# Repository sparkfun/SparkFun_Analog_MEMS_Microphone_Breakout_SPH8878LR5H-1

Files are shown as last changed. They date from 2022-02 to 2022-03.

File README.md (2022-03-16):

SparkFun Analog MEMS Microphone Breakout - SPH8878LR5H-1
========================================

SparkFun MEMS Microphone Breakout (ICS-40180) (https://www.sparkfun.com/products/19389)

[*SparkFun MEMS Microphone Breakout (ICS-40180) [BOB-18011]*](https://www.sparkfun.com/products/19389)

The SparkFun Analog MEMS Microphone Breakout makes it easy to work with the SPH8878LR5H-1 analog microphone from Knowles. This board features an OpAmp to bring output of the microphone to a usable level, allowing you to plug directly into an ADC on a microcontroller or something like the [SparkFun Spectrum Shield](https://www.sparkfun.com/products/13116).

In addition to amplifying the signal, the OpAmp adds a bias voltage of 1/2 VCC. With sound sources such as a normal speaking voice a few feet away from the microphone, the AUD output signal will be at about 200mV peak-to-peak. Also note, this low profile microphone has its port on the bottom side, so the microphone can be mounted flush to the outer surface of your enclosure. This microphone is omni-directional, which means it does a good job of picking up sound sources from all directions.

Repository Contents
-------------------

* **/Documentation** - Data sheets, additional product information
* **/Hardware** - Eagle design files (.brd, .sch)
* **/Hardware/Production** - Production panel files (.brd)

Documentation
--------------
* **[Hookup Guide](https://learn.sparkfun.com/tutorials/analog-mems-microphone-breakout---sph8878lr5h-1-hookup-guide)** - Basic hookup guide for the SparkFun MEMS microphone breakout.

Product Versions
---------------
* **[BOB-09868](https://www.sparkfun.com/products/retired/9868)** - SparkFun MEMS Microphone Breakout - INMP401 (ADMP401)
* **[BOB-18011](https://www.sparkfun.com/products/18011)** - SparkFun Analog MEMS Microphone Breakout - ICS-40180 
* **[BOB-19389](https://www.sparkfun.com/products/19389)** -  SparkFun Analog MEMS Microphone Breakout - SPH8878LR5H-1

License Information
-------------------

This product is _**open source**_! 

Please review the LICENSE.md file for license information. 

If you have any questions or concerns on licensing, please contact technical support on our [SparkFun forums](https://forum.sparkfun.com/viewforum.php?f=152).

Distributed as-is; no warranty is given.

- Your friends at SparkFun.

_<COLLABORATION CREDIT>_

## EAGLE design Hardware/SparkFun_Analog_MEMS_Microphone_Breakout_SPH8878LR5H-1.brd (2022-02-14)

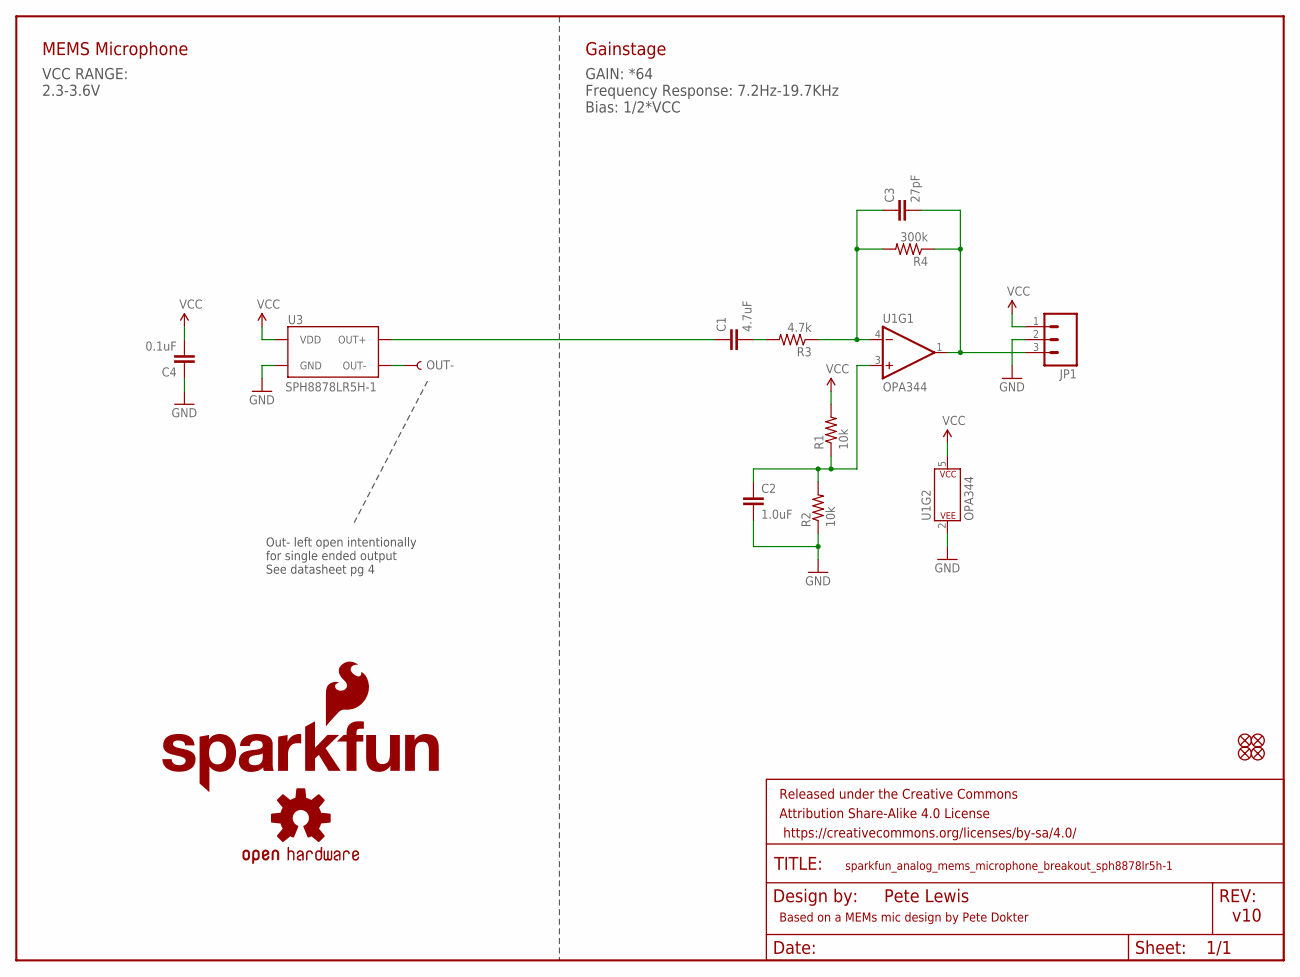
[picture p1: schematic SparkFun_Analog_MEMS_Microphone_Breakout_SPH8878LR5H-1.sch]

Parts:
C1: 4.7uF; 0603
C2: 1.0uF; 0603
C3: 27pF; 0603
C4: 0.1uF; 0603
FD1, FD2, FD3, FD4: FIDUCIALUFIDUCIAL; FIDUCIAL-MICRO
FRAME2: FRAME-LETTER; CREATIVE_COMMONS
JP1: CONN_031X03_NO_SILK; 1X03_NO_SILK
LOGO1: SFE_LOGO_FLAME.1_INCH; SFE_LOGO_FLAME_.1
LOGO2: OSHW-LOGOMINI; OSHW-LOGO-MINI
OUT-: TEST-POINTTP_15TH_THRU; TP_15TH
R1, R2: 10k; 0603
R3: 4.7k; 0603
R4: 300k; 0603
U1: OPA344; SOT23-5
U3: SPH8878LR5H-1

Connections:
AUD: C3.2, JP1.3, R4.1, U1.1 (OUT)
GND: C2.2, C4.1, JP1.2, R2.1, U1.2 (P$V-), U3.2 (GND), U3.3 (GND), U3.4 (GND)
unnamed: C1.1, U3.1 (OUT+)
unnamed: C3.1, R3.1, R4.2, U1.4 (-IN)
unnamed: OUT-.1, U3.6 (OUT-)
unnamed: C1.2, R3.2
unnamed: C2.1, R1.1, R2.2, U1.3 (+IN)
VCC: C4.2, JP1.1, R1.2, U1.5 (P$V+), U3.5 (VDD)

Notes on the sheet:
v10
Pete Lewis
VCC RANGE: 2.3-3.6V
MEMS Microphone
Gainstage
GAIN: *64 Frequency Response: 7.2Hz-19.7KHz Bias: 1/2*VCC
Out- left open intentionally for single ended output See datasheet pg 4
Based on a MEMs mic design by Pete Dokter

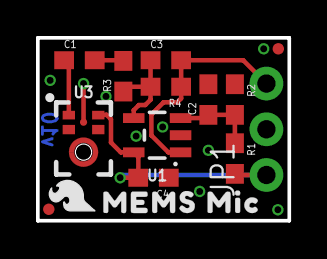
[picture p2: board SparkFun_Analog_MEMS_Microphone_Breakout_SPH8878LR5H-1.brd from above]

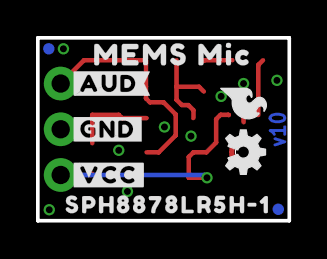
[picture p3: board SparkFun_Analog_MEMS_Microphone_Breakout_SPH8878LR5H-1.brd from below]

Board: 2 copper layers, 14.0 x 10.2 mm, 26 parts (10 on the bottom side), 8 nets.

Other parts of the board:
LOGO3: SFE_LOGO_FLAME.1_INCH; SFE_LOGO_FLAME_.1
U$2, U$7: MEMS_MIC0
U$3: #GND#0
U$4: #VCC#0
U$5: #AUD#0
U$9: SPH8878LR5H#10

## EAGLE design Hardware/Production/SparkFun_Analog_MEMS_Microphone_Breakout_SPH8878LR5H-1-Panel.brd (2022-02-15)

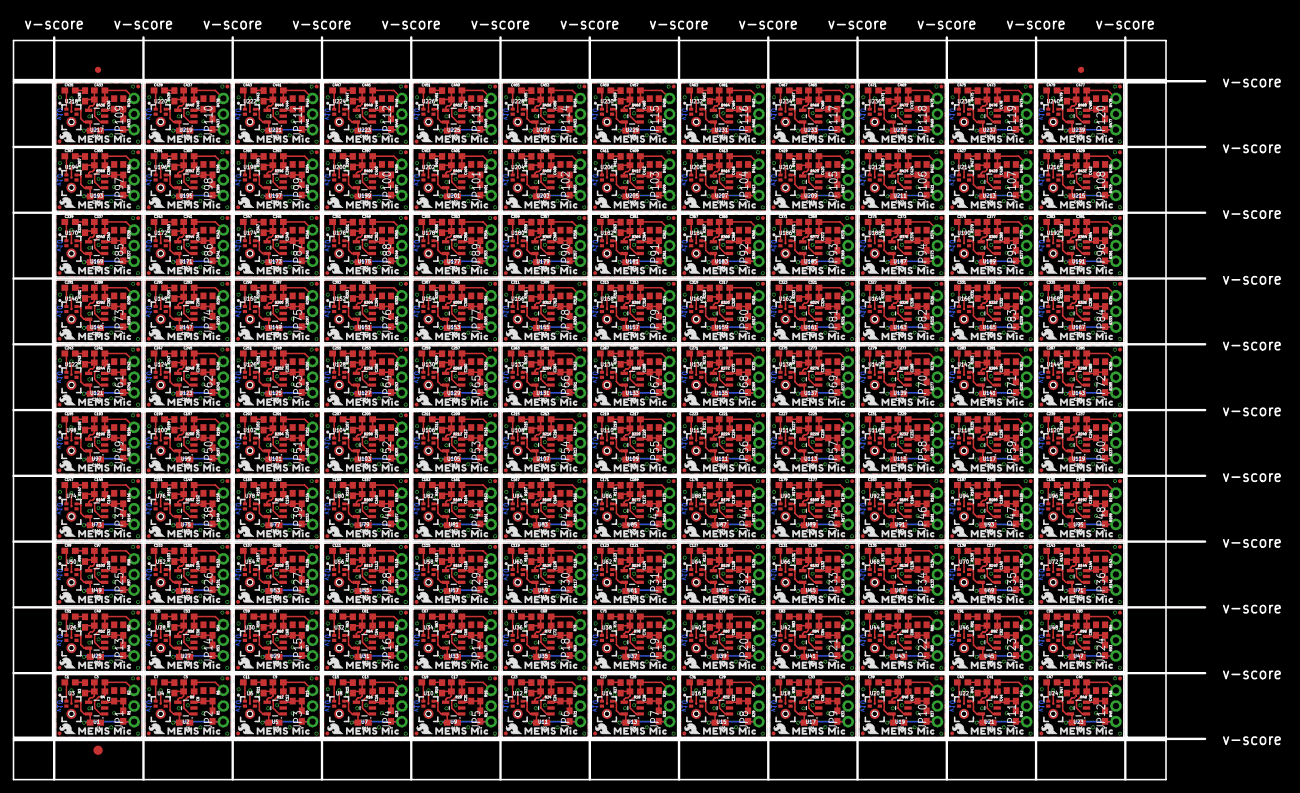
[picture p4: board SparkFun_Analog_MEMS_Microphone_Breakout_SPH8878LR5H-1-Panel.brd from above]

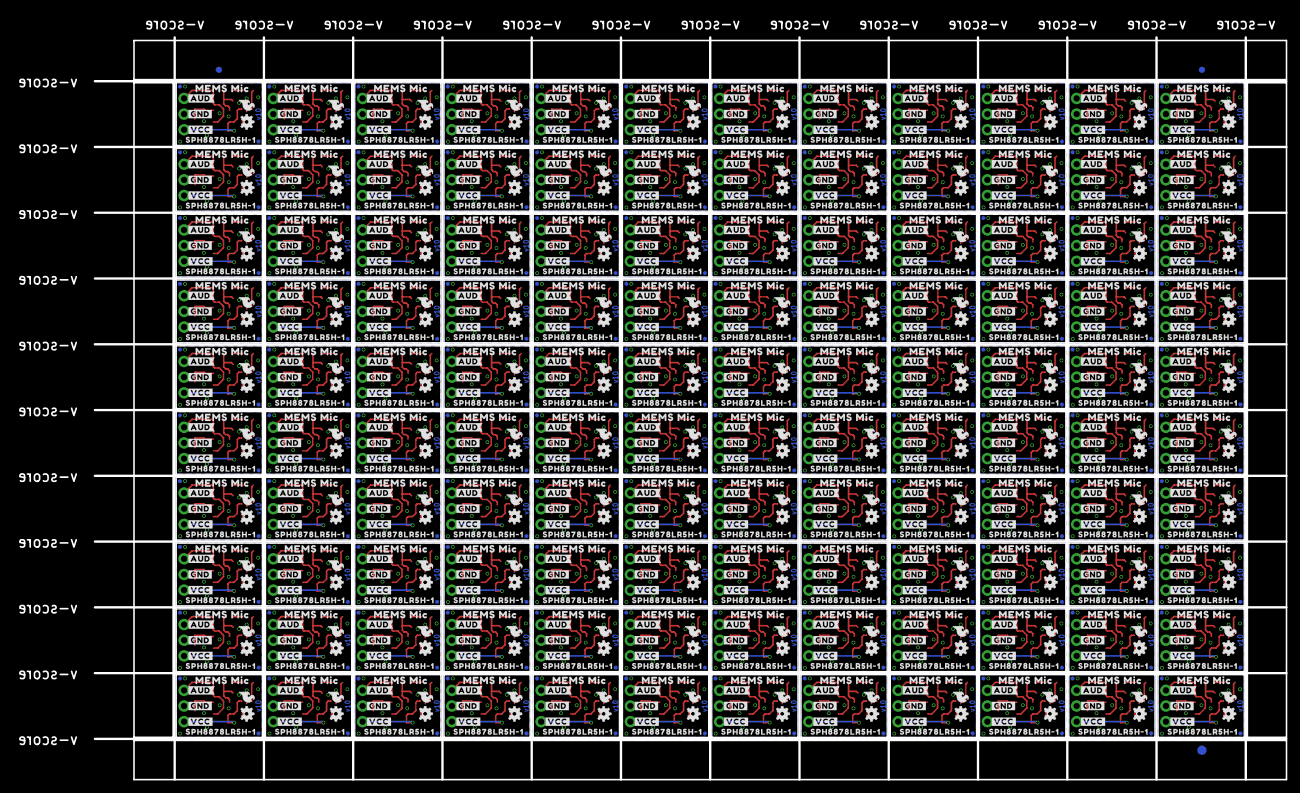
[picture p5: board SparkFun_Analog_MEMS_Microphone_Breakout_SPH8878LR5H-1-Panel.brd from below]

Board: 2 copper layers, 193.3 x 120.4 mm, 3006 parts (1203 on the bottom side), 960 nets.

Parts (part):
C1, C7, C11, C15, C19, C23, C27, C31, C35, C39, C43, C47, C51, C55, C59, C63, C67, C71, C75, C79, C83, C87, C91, C95, C99, C103, C107, C111, C115, C119, C123, C127, C131, C135, C139, C143, C147, C151, C155, C159, C163, C167, C171, C175, C179, C183, C187, C191, C195, C199, C203, C207, C211, C215, C219, C223, C227, C231, C235, C239, C243, C247, C251, C255, C259, C263, C267, C271, C275, C279, C283, C287, C291, C295, C299, C303, C307, C311, C315, C319, C323, C327, C331, C335, C339, C343, C347, C351, C355, C359, C363, C367, C371, C375, C379, C383, C387, C391, C395, C399, C403, C407, C411, C415, C419, C423, C427, C431, C435, C439, C443, C447, C451, C455, C459, C463, C467, C471, C475, C479: 4.7uF; 0603
C2, C8, C12, C16, C20, C24, C28, C32, C36, C40, C44, C48, C52, C56, C60, C64, C68, C72, C76, C80, C84, C88, C92, C96, C100, C104, C108, C112, C116, C120, C124, C128, C132, C136, C140, C144, C148, C152, C156, C160, C164, C168, C172, C176, C180, C184, C188, C192, C196, C200, C204, C208, C212, C216, C220, C224, C228, C232, C236, C240, C244, C248, C252, C256, C260, C264, C268, C272, C276, C280, C284, C288, C292, C296, C300, C304, C308, C312, C316, C320, C324, C328, C332, C336, C340, C344, C348, C352, C356, C360, C364, C368, C372, C376, C380, C384, C388, C392, C396, C400, C404, C408, C412, C416, C420, C424, C428, C432, C436, C440, C444, C448, C452, C456, C460, C464, C468, C472, C476, C480: 1.0uF; 0603
C3, C5, C9, C13, C17, C21, C25, C29, C33, C37, C41, C45, C49, C53, C57, C61, C65, C69, C73, C77, C81, C85, C89, C93, C97, C101, C105, C109, C113, C117, C121, C125, C129, C133, C137, C141, C145, C149, C153, C157, C161, C165, C169, C173, C177, C181, C185, C189, C193, C197, C201, C205, C209, C213, C217, C221, C225, C229, C233, C237, C241, C245, C249, C253, C257, C261, C265, C269, C273, C277, C281, C285, C289, C293, C297, C301, C305, C309, C313, C317, C321, C325, C329, C333, C337, C341, C345, C349, C353, C357, C361, C365, C369, C373, C377, C381, C385, C389, C393, C397, C401, C405, C409, C413, C417, C421, C425, C429, C433, C437, C441, C445, C449, C453, C457, C461, C465, C469, C473, C477: 27pF; 0603
C4, C6, C10, C14, C18, C22, C26, C30, C34, C38, C42, C46, C50, C54, C58, C62, C66, C70, C74, C78, C82, C86, C90, C94, C98, C102, C106, C110, C114, C118, C122, C126, C130, C134, C138, C142, C146, C150, C154, C158, C162, C166, C170, C174, C178, C182, C186, C190, C194, C198, C202, C206, C210, C214, C218, C222, C226, C230, C234, C238, C242, C246, C250, C254, C258, C262, C266, C270, C274, C278, C282, C286, C290, C294, C298, C302, C306, C310, C314, C318, C322, C326, C330, C334, C338, C342, C346, C350, C354, C358, C362, C366, C370, C374, C378, C382, C386, C390, C394, C398, C402, C406, C410, C414, C418, C422, C426, C430, C434, C438, C442, C446, C450, C454, C458, C462, C466, C470, C474, C478: 0.1uF; 0603
E$1, E$2, E$3, E$4: FIDUCIAL-1X2
E$5, E$6: FIDUCIAL-1.5X3
FD1, FD2, FD3, FD4, FD5, FD6, FD7, FD8, FD9, FD10, FD11, FD12, FD13, FD14, FD15, FD16, FD17, FD18, FD19, FD20, FD21, FD22, FD23, FD24, FD25, FD26, FD27, FD28, FD29, FD30, FD31, FD32, FD33, FD34, FD35, FD36, FD37, FD38, FD39, FD40, FD41, FD42, FD43, FD44, FD45, FD46, FD47, FD48, FD49, FD50, FD51, FD52, FD53, FD54, FD55, FD56, FD57, FD58, FD59, FD60, FD61, FD62, FD63, FD64, FD65, FD66, FD67, FD68, FD69, FD70, FD71, FD72, FD73, FD74, FD75, FD76, FD77, FD78, FD79, FD80, FD81, FD82, FD83, FD84, FD85, FD86, FD87, FD88, FD89, FD90, FD91, FD92, FD93, FD94, FD95, FD96, FD97, FD98, FD99, FD100, FD101, FD102, FD103, FD104, FD105, FD106, FD107, FD108, FD109, FD110, FD111, FD112, FD113, FD114, FD115, FD116, FD117, FD118, FD119, FD120, FD121, FD122, FD123, FD124, FD125, FD126, FD127, FD128, FD129, FD130, FD131, FD132, FD133, FD134, FD135, FD136, FD137, FD138, FD139, FD140, FD141, FD142, FD143, FD144, FD145, FD146, FD147, FD148, FD149, FD150, FD151, FD152, FD153, FD154, FD155, FD156, FD157, FD158, FD159, FD160, FD161, FD162, FD163, FD164, FD165, FD166, FD167, FD168, FD169, FD170, FD171, FD172, FD173, FD174, FD175, FD176, FD177, FD178, FD179, FD180, FD181, FD182, FD183, FD184, FD185, FD186, FD187, FD188, FD189, FD190, FD191, FD192, FD193, FD194, FD195, FD196, FD197, FD198, FD199, FD200, FD201, FD202, FD203, FD204, FD205, FD206, FD207, FD208, FD209, FD210, FD211, FD212, FD213, FD214, FD215, FD216, FD217, FD218, FD219, FD220, FD221, FD222, FD223, FD224, FD225, FD226, FD227, FD228, FD229, FD230, FD231, FD232, FD233, FD234, FD235, FD236, FD237, FD238, FD239, FD240, FD241, FD242, FD243, FD244, FD245, FD246, FD247, FD248, FD249, FD250, FD251, FD252, FD253, FD254, FD255, FD256, FD257, FD258, FD259, FD260, FD261, FD262, FD263, FD264, FD265, FD266, FD267, FD268, FD269, FD270, FD271, FD272, FD273, FD274, FD275, FD276, FD277, FD278, FD279, FD280, FD281, FD282, FD283, FD284, FD285, FD286, FD287, FD288, FD289, FD290, FD291, FD292, FD293, FD294, FD295, FD296, FD297, FD298, FD299, FD300, FD301, FD302, FD303, FD304, FD305, FD306, FD307, FD308, FD309, FD310, FD311, FD312, FD313, FD314, FD315, FD316, FD317, FD318, FD319, FD320, FD321, FD322, FD323, FD324, FD325, FD326, FD327, FD328, FD329, FD330, FD331, FD332, FD333, FD334, FD335, FD336, FD337, FD338, FD339, FD340, FD341, FD342, FD343, FD344, FD345, FD346, FD347, FD348, FD349, FD350, FD351, FD352, FD353, FD354, FD355, FD356, FD357, FD358, FD359, FD360, FD361, FD362, FD363, FD364, FD365, FD366, FD367, FD368, FD369, FD370, FD371, FD372, FD373, FD374, FD375, FD376, FD377, FD378, FD379, FD380, FD381, FD382, FD383, FD384, FD385, FD386, FD387, FD388, FD389, FD390, FD391, FD392, FD393, FD394, FD395, FD396, FD397, FD398, FD399, FD400, FD401, FD402, FD403, FD404, FD405, FD406, FD407, FD408, FD409, FD410, FD411, FD412, FD413, FD414, FD415, FD416, FD417, FD418, FD419, FD420, FD421, FD422, FD423, FD424, FD425, FD426, FD427, FD428, FD429, FD430, FD431, FD432, FD433, FD434, FD435, FD436, FD437, FD438, FD439, FD440, FD441, FD442, FD443, FD444, FD445, FD446, FD447, FD448, FD449, FD450, FD451, FD452, FD453, FD454, FD455, FD456, FD457, FD458, FD459, FD460, FD461, FD462, FD463, FD464, FD465, FD466, FD467, FD468, FD469, FD470, FD471, FD472, FD473, FD474, FD475, FD476, FD477, FD478, FD479, FD480: FIDUCIALUFIDUCIAL; FIDUCIAL-MICRO
JP1, JP2, JP3, JP4, JP5, JP6, JP7, JP8, JP9, JP10, JP11, JP12, JP13, JP14, JP15, JP16, JP17, JP18, JP19, JP20, JP21, JP22, JP23, JP24, JP25, JP26, JP27, JP28, JP29, JP30, JP31, JP32, JP33, JP34, JP35, JP36, JP37, JP38, JP39, JP40, JP41, JP42, JP43, JP44, JP45, JP46, JP47, JP48, JP49, JP50, JP51, JP52, JP53, JP54, JP55, JP56, JP57, JP58, JP59, JP60, JP61, JP62, JP63, JP64, JP65, JP66, JP67, JP68, JP69, JP70, JP71, JP72, JP73, JP74, JP75, JP76, JP77, JP78, JP79, JP80, JP81, JP82, JP83, JP84, JP85, JP86, JP87, JP88, JP89, JP90, JP91, JP92, JP93, JP94, JP95, JP96, JP97, JP98, JP99, JP100, JP101, JP102, JP103, JP104, JP105, JP106, JP107, JP108, JP109, JP110, JP111, JP112, JP113, JP114, JP115, JP116, JP117, JP118, JP119, JP120: 1X03_NO_SILK
LOGO1, LOGO3, LOGO4, LOGO6, LOGO7, LOGO9, LOGO10, LOGO12, LOGO13, LOGO15, LOGO16, LOGO18, LOGO19, LOGO21, LOGO22, LOGO24, LOGO25, LOGO27, LOGO28, LOGO30, LOGO31, LOGO33, LOGO34, LOGO36, LOGO37, LOGO39, LOGO40, LOGO42, LOGO43, LOGO45, LOGO46, LOGO48, LOGO49, LOGO51, LOGO52, LOGO54, LOGO55, LOGO57, LOGO58, LOGO60, LOGO61, LOGO63, LOGO64, LOGO66, LOGO67, LOGO69, LOGO70, LOGO72, LOGO73, LOGO75, LOGO76, LOGO78, LOGO79, LOGO81, LOGO82, LOGO84, LOGO85, LOGO87, LOGO88, LOGO90, LOGO91, LOGO93, LOGO94, LOGO96, LOGO97, LOGO99, LOGO100, LOGO102, LOGO103, LOGO105, LOGO106, LOGO108, LOGO109, LOGO111, LOGO112, LOGO114, LOGO115, LOGO117, LOGO118, LOGO120, LOGO121, LOGO123, LOGO124, LOGO126, LOGO127, LOGO129, LOGO130, LOGO132, LOGO133, LOGO135, LOGO136, LOGO138, LOGO139, LOGO141, LOGO142, LOGO144, LOGO145, LOGO147, LOGO148, LOGO150, LOGO151, LOGO153, LOGO154, LOGO156, LOGO157, LOGO159, LOGO160, LOGO162, LOGO163, LOGO165, LOGO166, LOGO168, LOGO169, LOGO171, LOGO172, LOGO174, LOGO175, LOGO177, LOGO178, LOGO180, LOGO181, LOGO183, LOGO184, LOGO186, LOGO187, LOGO189, LOGO190, LOGO192, LOGO193, LOGO195, LOGO196, LOGO198, LOGO199, LOGO201, LOGO202, LOGO204, LOGO205, LOGO207, LOGO208, LOGO210, LOGO211, LOGO213, LOGO214, LOGO216, LOGO217, LOGO219, LOGO220, LOGO222, LOGO223, LOGO225, LOGO226, LOGO228, LOGO229, LOGO231, LOGO232, LOGO234, LOGO235, LOGO237, LOGO238, LOGO240, LOGO241, LOGO243, LOGO244, LOGO246, LOGO247, LOGO249, LOGO250, LOGO252, LOGO253, LOGO255, LOGO256, LOGO258, LOGO259, LOGO261, LOGO262, LOGO264, LOGO265, LOGO267, LOGO268, LOGO270, LOGO271, LOGO273, LOGO274, LOGO276, LOGO277, LOGO279, LOGO280, LOGO282, LOGO283, LOGO285, LOGO286, LOGO288, LOGO289, LOGO291, LOGO292, LOGO294, LOGO295, LOGO297, LOGO298, LOGO300, LOGO301, LOGO303, LOGO304, LOGO306, LOGO307, LOGO309, LOGO310, LOGO312, LOGO313, LOGO315, LOGO316, LOGO318, LOGO319, LOGO321, LOGO322, LOGO324, LOGO325, LOGO327, LOGO328, LOGO330, LOGO331, LOGO333, LOGO334, LOGO336, LOGO337, LOGO339, LOGO340, LOGO342, LOGO343, LOGO345, LOGO346, LOGO348, LOGO349, LOGO351, LOGO352, LOGO354, LOGO355, LOGO357, LOGO358, LOGO360: SFE_LOGO_FLAME.1_INCH; SFE_LOGO_FLAME_.1
LOGO2, LOGO5, LOGO8, LOGO11, LOGO14, LOGO17, LOGO20, LOGO23, LOGO26, LOGO29, LOGO32, LOGO35, LOGO38, LOGO41, LOGO44, LOGO47, LOGO50, LOGO53, LOGO56, LOGO59, LOGO62, LOGO65, LOGO68, LOGO71, LOGO74, LOGO77, LOGO80, LOGO83, LOGO86, LOGO89, LOGO92, LOGO95, LOGO98, LOGO101, LOGO104, LOGO107, LOGO110, LOGO113, LOGO116, LOGO119, LOGO122, LOGO125, LOGO128, LOGO131, LOGO134, LOGO137, LOGO140, LOGO143, LOGO146, LOGO149, LOGO152, LOGO155, LOGO158, LOGO161, LOGO164, LOGO167, LOGO170, LOGO173, LOGO176, LOGO179, LOGO182, LOGO185, LOGO188, LOGO191, LOGO194, LOGO197, LOGO200, LOGO203, LOGO206, LOGO209, LOGO212, LOGO215, LOGO218, LOGO221, LOGO224, LOGO227, LOGO230, LOGO233, LOGO236, LOGO239, LOGO242, LOGO245, LOGO248, LOGO251, LOGO254, LOGO257, LOGO260, LOGO263, LOGO266, LOGO269, LOGO272, LOGO275, LOGO278, LOGO281, LOGO284, LOGO287, LOGO290, LOGO293, LOGO296, LOGO299, LOGO302, LOGO305, LOGO308, LOGO311, LOGO314, LOGO317, LOGO320, LOGO323, LOGO326, LOGO329, LOGO332, LOGO335, LOGO338, LOGO341, LOGO344, LOGO347, LOGO350, LOGO353, LOGO356, LOGO359: OSHW-LOGOMINI; OSHW-LOGO-MINI
OUT-, OUT-1, OUT-2, OUT-3, OUT-4, OUT-5, OUT-6, OUT-7, OUT-8, OUT-9, OUT-10, OUT-11, OUT-12, OUT-13, OUT-14, OUT-15, OUT-16, OUT-17, OUT-18, OUT-19, OUT-20, OUT-21, OUT-22, OUT-23, OUT-24, OUT-25, OUT-26, OUT-27, OUT-28, OUT-29, OUT-30, OUT-31, OUT-32, OUT-33, OUT-34, OUT-35, OUT-36, OUT-37, OUT-38, OUT-39, OUT-40, OUT-41, OUT-42, OUT-43, OUT-44, OUT-45, OUT-46, OUT-47, OUT-48, OUT-49, OUT-50, OUT-51, OUT-52, OUT-53, OUT-54, OUT-55, OUT-56, OUT-57, OUT-58, OUT-59, OUT-60, OUT-61, OUT-62, OUT-63, OUT-64, OUT-65, OUT-66, OUT-67, OUT-68, OUT-69, OUT-70, OUT-71, OUT-72, OUT-73, OUT-74, OUT-75, OUT-76, OUT-77, OUT-78, OUT-79, OUT-80, OUT-81, OUT-82, OUT-83, OUT-84, OUT-85, OUT-86, OUT-87, OUT-88, OUT-89, OUT-90, OUT-91, OUT-92, OUT-93, OUT-94, OUT-95, OUT-96, OUT-97, OUT-98, OUT-99, OUT-100, OUT-101, OUT-102, OUT-103, OUT-104, OUT-105, OUT-106, OUT-107, OUT-108, OUT-109, OUT-110, OUT-111, OUT-112, OUT-113, OUT-114, OUT-115, OUT-116, OUT-117, OUT-118, OUT-119: TP_15TH
R1, R2, R5, R6, R9, R10, R13, R14, R17, R18, R21, R22, R25, R26, R29, R30, R33, R34, R37, R38, R41, R42, R45, R46, R49, R50, R53, R54, R57, R58, R61, R62, R65, R66, R69, R70, R73, R74, R77, R78, R81, R82, R85, R86, R89, R90, R93, R94, R97, R98, R101, R102, R105, R106, R109, R110, R113, R114, R117, R118, R121, R122, R125, R126, R129, R130, R133, R134, R137, R138, R141, R142, R145, R146, R149, R150, R153, R154, R157, R158, R161, R162, R165, R166, R169, R170, R173, R174, R177, R178, R181, R182, R185, R186, R189, R190, R193, R194, R197, R198, R201, R202, R205, R206, R209, R210, R213, R214, R217, R218, R221, R222, R225, R226, R229, R230, R233, R234, R237, R238, R241, R242, R245, R246, R249, R250, R253, R254, R257, R258, R261, R262, R265, R266, R269, R270, R273, R274, R277, R278, R281, R282, R285, R286, R289, R290, R293, R294, R297, R298, R301, R302, R305, R306, R309, R310, R313, R314, R317, R318, R321, R322, R325, R326, R329, R330, R333, R334, R337, R338, R341, R342, R345, R346, R349, R350, R353, R354, R357, R358, R361, R362, R365, R366, R369, R370, R373, R374, R377, R378, R381, R382, R385, R386, R389, R390, R393, R394, R397, R398, R401, R402, R405, R406, R409, R410, R413, R414, R417, R418, R421, R422, R425, R426, R429, R430, R433, R434, R437, R438, R441, R442, R445, R446, R449, R450, R453, R454, R457, R458, R461, R462, R465, R466, R469, R470, R473, R474, R477, R478: 10k; 0603
R3, R7, R11, R15, R19, R23, R27, R31, R35, R39, R43, R47, R51, R55, R59, R63, R67, R71, R75, R79, R83, R87, R91, R95, R99, R103, R107, R111, R115, R119, R123, R127, R131, R135, R139, R143, R147, R151, R155, R159, R163, R167, R171, R175, R179, R183, R187, R191, R195, R199, R203, R207, R211, R215, R219, R223, R227, R231, R235, R239, R243, R247, R251, R255, R259, R263, R267, R271, R275, R279, R283, R287, R291, R295, R299, R303, R307, R311, R315, R319, R323, R327, R331, R335, R339, R343, R347, R351, R355, R359, R363, R367, R371, R375, R379, R383, R387, R391, R395, R399, R403, R407, R411, R415, R419, R423, R427, R431, R435, R439, R443, R447, R451, R455, R459, R463, R467, R471, R475, R479: 4.7k; 0603
R4, R8, R12, R16, R20, R24, R28, R32, R36, R40, R44, R48, R52, R56, R60, R64, R68, R72, R76, R80, R84, R88, R92, R96, R100, R104, R108, R112, R116, R120, R124, R128, R132, R136, R140, R144, R148, R152, R156, R160, R164, R168, R172, R176, R180, R184, R188, R192, R196, R200, R204, R208, R212, R216, R220, R224, R228, R232, R236, R240, R244, R248, R252, R256, R260, R264, R268, R272, R276, R280, R284, R288, R292, R296, R300, R304, R308, R312, R316, R320, R324, R328, R332, R336, R340, R344, R348, R352, R356, R360, R364, R368, R372, R376, R380, R384, R388, R392, R396, R400, R404, R408, R412, R416, R420, R424, R428, R432, R436, R440, R444, R448, R452, R456, R460, R464, R468, R472, R476, R480: 300k; 0603
U1, U2, U5, U7, U9, U11, U13, U15, U17, U19, U21, U23, U25, U27, U29, U31, U33, U35, U37, U39, U41, U43, U45, U47, U49, U51, U53, U55, U57, U59, U61, U63, U65, U67, U69, U71, U73, U75, U77, U79, U81, U83, U85, U87, U89, U91, U93, U95, U97, U99, U101, U103, U105, U107, U109, U111, U113, U115, U117, U119, U121, U123, U125, U127, U129, U131, U133, U135, U137, U139, U141, U143, U145, U147, U149, U151, U153, U155, U157, U159, U161, U163, U165, U167, U169, U171, U173, U175, U177, U179, U181, U183, U185, U187, U189, U191, U193, U195, U197, U199, U201, U203, U205, U207, U209, U211, U213, U215, U217, U219, U221, U223, U225, U227, U229, U231, U233, U235, U237, U239: OPA344; SOT23-5
U3, U4, U6, U8, U10, U12, U14, U16, U18, U20, U22, U24, U26, U28, U30, U32, U34, U36, U38, U40, U42, U44, U46, U48, U50, U52, U54, U56, U58, U60, U62, U64, U66, U68, U70, U72, U74, U76, U78, U80, U82, U84, U86, U88, U90, U92, U94, U96, U98, U100, U102, U104, U106, U108, U110, U112, U114, U116, U118, U120, U122, U124, U126, U128, U130, U132, U134, U136, U138, U140, U142, U144, U146, U148, U150, U152, U154, U156, U158, U160, U162, U164, U166, U168, U170, U172, U174, U176, U178, U180, U182, U184, U186, U188, U190, U192, U194, U196, U198, U200, U202, U204, U206, U208, U210, U212, U214, U216, U218, U220, U222, U224, U226, U228, U230, U232, U234, U236, U238, U240: SPH8878LR5H-1
U$1, U$2, U$7, U$11, U$13, U$17, U$19, U$23, U$25, U$29, U$31, U$35, U$37, U$41, U$43, U$47, U$49, U$53, U$55, U$59, U$61, U$65, U$67, U$71, U$73, U$77, U$79, U$83, U$85, U$89, U$91, U$95, U$97, U$101, U$103, U$107, U$109, U$113, U$115, U$119, U$121, U$125, U$127, U$131, U$133, U$137, U$139, U$143, U$145, U$149, U$151, U$155, U$157, U$161, U$163, U$167, U$169, U$173, U$175, U$179, U$181, U$185, U$187, U$191, U$193, U$197, U$199, U$203, U$205, U$209, U$211, U$215, U$217, U$221, U$223, U$227, U$229, U$233, U$235, U$239, U$241, U$245, U$247, U$251, U$253, U$257, U$259, U$263, U$265, U$269, U$271, U$275, U$277, U$281, U$283, U$287, U$289, U$293, U$295, U$299, U$301, U$305, U$307, U$311, U$313, U$317, U$319, U$323, U$325, U$329, U$331, U$335, U$337, U$341, U$343, U$347, U$349, U$353, U$355, U$359, U$361, U$365, U$367, U$371, U$373, U$377, U$379, U$383, U$385, U$389, U$391, U$395, U$397, U$401, U$403, U$407, U$409, U$413, U$415, U$419, U$421, U$425, U$427, U$431, U$433, U$437, U$439, U$443, U$445, U$449, U$451, U$455, U$457, U$461, U$463, U$467, U$469, U$473, U$475, U$479, U$481, U$485, U$487, U$491, U$493, U$497, U$499, U$503, U$505, U$509, U$511, U$515, U$517, U$521, U$523, U$527, U$529, U$533, U$535, U$539, U$541, U$545, U$547, U$551, U$553, U$557, U$559, U$563, U$565, U$569, U$571, U$575, U$577, U$581, U$583, U$587, U$589, U$593, U$595, U$599, U$601, U$605, U$607, U$611, U$613, U$617, U$619, U$623, U$625, U$629, U$631, U$635, U$637, U$641, U$643, U$647, U$649, U$653, U$655, U$659, U$661, U$665, U$667, U$671, U$673, U$677, U$679, U$683, U$685, U$689, U$691, U$695, U$697, U$701, U$703, U$707, U$709, U$713, U$715, U$719: MEMS_MIC0
U$3, U$6, U$14, U$20, U$26, U$32, U$38, U$44, U$50, U$56, U$62, U$68, U$74, U$80, U$86, U$92, U$98, U$104, U$110, U$116, U$122, U$128, U$134, U$140, U$146, U$152, U$158, U$164, U$170, U$176, U$182, U$188, U$194, U$200, U$206, U$212, U$218, U$224, U$230, U$236, U$242, U$248, U$254, U$260, U$266, U$272, U$278, U$284, U$290, U$296, U$302, U$308, U$314, U$320, U$326, U$332, U$338, U$344, U$350, U$356, U$362, U$368, U$374, U$380, U$386, U$392, U$398, U$404, U$410, U$416, U$422, U$428, U$434, U$440, U$446, U$452, U$458, U$464, U$470, U$476, U$482, U$488, U$494, U$500, U$506, U$512, U$518, U$524, U$530, U$536, U$542, U$548, U$554, U$560, U$566, U$572, U$578, U$584, U$590, U$596, U$602, U$608, U$614, U$620, U$626, U$632, U$638, U$644, U$650, U$656, U$662, U$668, U$674, U$680, U$686, U$692, U$698, U$704, U$710, U$716: #GND#0
U$4, U$8, U$15, U$21, U$27, U$33, U$39, U$45, U$51, U$57, U$63, U$69, U$75, U$81, U$87, U$93, U$99, U$105, U$111, U$117, U$123, U$129, U$135, U$141, U$147, U$153, U$159, U$165, U$171, U$177, U$183, U$189, U$195, U$201, U$207, U$213, U$219, U$225, U$231, U$237, U$243, U$249, U$255, U$261, U$267, U$273, U$279, U$285, U$291, U$297, U$303, U$309, U$315, U$321, U$327, U$333, U$339, U$345, U$351, U$357, U$363, U$369, U$375, U$381, U$387, U$393, U$399, U$405, U$411, U$417, U$423, U$429, U$435, U$441, U$447, U$453, U$459, U$465, U$471, U$477, U$483, U$489, U$495, U$501, U$507, U$513, U$519, U$525, U$531, U$537, U$543, U$549, U$555, U$561, U$567, U$573, U$579, U$585, U$591, U$597, U$603, U$609, U$615, U$621, U$627, U$633, U$639, U$645, U$651, U$657, U$663, U$669, U$675, U$681, U$687, U$693, U$699, U$705, U$711, U$717: #VCC#0
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

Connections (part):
AUD: C3.2, JP1.3, R4.1, U1.1
AUD1: C5.2, JP2.3, R8.1, U2.1
AUD2: C9.2, JP3.3, R12.1, U5.1
AUD3: C13.2, JP4.3, R16.1, U7.1
AUD4: C17.2, JP5.3, R20.1, U9.1
AUD5: C21.2, JP6.3, R24.1, U11.1
AUD6: C25.2, JP7.3, R28.1, U13.1
AUD7: C29.2, JP8.3, R32.1, U15.1
AUD8: C33.2, JP9.3, R36.1, U17.1
AUD9: C37.2, JP10.3, R40.1, U19.1
AUD10: C41.2, JP11.3, R44.1, U21.1
AUD11: C45.2, JP12.3, R48.1, U23.1
AUD12: C49.2, JP13.3, R52.1, U25.1
AUD13: C53.2, JP14.3, R56.1, U27.1
AUD14: C57.2, JP15.3, R60.1, U29.1
AUD15: C61.2, JP16.3, R64.1, U31.1
AUD16: C65.2, JP17.3, R68.1, U33.1
AUD17: C69.2, JP18.3, R72.1, U35.1
AUD18: C73.2, JP19.3, R76.1, U37.1
AUD19: C77.2, JP20.3, R80.1, U39.1
AUD20: C81.2, JP21.3, R84.1, U41.1
AUD21: C85.2, JP22.3, R88.1, U43.1
AUD22: C89.2, JP23.3, R92.1, U45.1
AUD23: C93.2, JP24.3, R96.1, U47.1
AUD24: C97.2, JP25.3, R100.1, U49.1
AUD25: C101.2, JP26.3, R104.1, U51.1
AUD26: C105.2, JP27.3, R108.1, U53.1
AUD27: C109.2, JP28.3, R112.1, U55.1
AUD28: C113.2, JP29.3, R116.1, U57.1
AUD29: C117.2, JP30.3, R120.1, U59.1
AUD30: C121.2, JP31.3, R124.1, U61.1
AUD31: C125.2, JP32.3, R128.1, U63.1
AUD32: C129.2, JP33.3, R132.1, U65.1
AUD33: C133.2, JP34.3, R136.1, U67.1
AUD34: C137.2, JP35.3, R140.1, U69.1
AUD35: C141.2, JP36.3, R144.1, U71.1
AUD36: C145.2, JP37.3, R148.1, U73.1
AUD37: C149.2, JP38.3, R152.1, U75.1
AUD38: C153.2, JP39.3, R156.1, U77.1
AUD39: C157.2, JP40.3, R160.1, U79.1
AUD40: C161.2, JP41.3, R164.1, U81.1
AUD41: C165.2, JP42.3, R168.1, U83.1
AUD42: C169.2, JP43.3, R172.1, U85.1
AUD43: C173.2, JP44.3, R176.1, U87.1
AUD44: C177.2, JP45.3, R180.1, U89.1
AUD45: C181.2, JP46.3, R184.1, U91.1
AUD46: C185.2, JP47.3, R188.1, U93.1
AUD47: C189.2, JP48.3, R192.1, U95.1
AUD48: C193.2, JP49.3, R196.1, U97.1
AUD49: C197.2, JP50.3, R200.1, U99.1
AUD50: C201.2, JP51.3, R204.1, U101.1
AUD51: C205.2, JP52.3, R208.1, U103.1
AUD52: C209.2, JP53.3, R212.1, U105.1
AUD53: C213.2, JP54.3, R216.1, U107.1
AUD54: C217.2, JP55.3, R220.1, U109.1
AUD55: C221.2, JP56.3, R224.1, U111.1
AUD56: C225.2, JP57.3, R228.1, U113.1
AUD57: C229.2, JP58.3, R232.1, U115.1
AUD58: C233.2, JP59.3, R236.1, U117.1
AUD59: C237.2, JP60.3, R240.1, U119.1
AUD60: C241.2, JP61.3, R244.1, U121.1
AUD61: C245.2, JP62.3, R248.1, U123.1
AUD62: C249.2, JP63.3, R252.1, U125.1
AUD63: C253.2, JP64.3, R256.1, U127.1
AUD64: C257.2, JP65.3, R260.1, U129.1
AUD65: C261.2, JP66.3, R264.1, U131.1
AUD66: C265.2, JP67.3, R268.1, U133.1
AUD67: C269.2, JP68.3, R272.1, U135.1
AUD68: C273.2, JP69.3, R276.1, U137.1
AUD69: C277.2, JP70.3, R280.1, U139.1
AUD70: C281.2, JP71.3, R284.1, U141.1
AUD71: C285.2, JP72.3, R288.1, U143.1
AUD72: C289.2, JP73.3, R292.1, U145.1
AUD73: C293.2, JP74.3, R296.1, U147.1
AUD74: C297.2, JP75.3, R300.1, U149.1
AUD75: C301.2, JP76.3, R304.1, U151.1
AUD76: C305.2, JP77.3, R308.1, U153.1
AUD77: C309.2, JP78.3, R312.1, U155.1
AUD78: C313.2, JP79.3, R316.1, U157.1
AUD79: C317.2, JP80.3, R320.1, U159.1
AUD80: C321.2, JP81.3, R324.1, U161.1
AUD81: C325.2, JP82.3, R328.1, U163.1
AUD82: C329.2, JP83.3, R332.1, U165.1
AUD83: C333.2, JP84.3, R336.1, U167.1
AUD84: C337.2, JP85.3, R340.1, U169.1
AUD85: C341.2, JP86.3, R344.1, U171.1
AUD86: C345.2, JP87.3, R348.1, U173.1
AUD87: C349.2, JP88.3, R352.1, U175.1
AUD88: C353.2, JP89.3, R356.1, U177.1
AUD89: C357.2, JP90.3, R360.1, U179.1
AUD90: C361.2, JP91.3, R364.1, U181.1
AUD91: C365.2, JP92.3, R368.1, U183.1
AUD92: C369.2, JP93.3, R372.1, U185.1
AUD93: C373.2, JP94.3, R376.1, U187.1
AUD94: C377.2, JP95.3, R380.1, U189.1
AUD95: C381.2, JP96.3, R384.1, U191.1
AUD96: C385.2, JP97.3, R388.1, U193.1
AUD97: C389.2, JP98.3, R392.1, U195.1
AUD98: C393.2, JP99.3, R396.1, U197.1
AUD99: C397.2, JP100.3, R400.1, U199.1
AUD100: C401.2, JP101.3, R404.1, U201.1
AUD101: C405.2, JP102.3, R408.1, U203.1
AUD102: C409.2, JP103.3, R412.1, U205.1
AUD103: C413.2, JP104.3, R416.1, U207.1
AUD104: C417.2, JP105.3, R420.1, U209.1
AUD105: C421.2, JP106.3, R424.1, U211.1
AUD106: C425.2, JP107.3, R428.1, U213.1
AUD107: C429.2, JP108.3, R432.1, U215.1
AUD108: C433.2, JP109.3, R436.1, U217.1
AUD109: C437.2, JP110.3, R440.1, U219.1
AUD110: C441.2, JP111.3, R444.1, U221.1
AUD111: C445.2, JP112.3, R448.1, U223.1
AUD112: C449.2, JP113.3, R452.1, U225.1
AUD113: C453.2, JP114.3, R456.1, U227.1
AUD114: C457.2, JP115.3, R460.1, U229.1
AUD115: C461.2, JP116.3, R464.1, U231.1
AUD116: C465.2, JP117.3, R468.1, U233.1
AUD117: C469.2, JP118.3, R472.1, U235.1
AUD118: C473.2, JP119.3, R476.1, U237.1
AUD119: C477.2, JP120.3, R480.1, U239.1
GND: C2.2, C4.1, JP1.2, R2.1, U1.2, U3.2, U3.3, U3.4
GND1: C6.1, C8.2, JP2.2, R6.1, U2.2, U4.2, U4.3, U4.4
GND2: C10.1, C12.2, JP3.2, R10.1, U5.2, U6.2, U6.3, U6.4
GND3: C14.1, C16.2, JP4.2, R14.1, U7.2, U8.2, U8.3, U8.4
GND4: C18.1, C20.2, JP5.2, R18.1, U9.2, U10.2, U10.3, U10.4
GND5: C22.1, C24.2, JP6.2, R22.1, U11.2, U12.2, U12.3, U12.4
GND6: C26.1, C28.2, JP7.2, R26.1, U13.2, U14.2, U14.3, U14.4
GND7: C30.1, C32.2, JP8.2, R30.1, U15.2, U16.2, U16.3, U16.4
GND8: C34.1, C36.2, JP9.2, R34.1, U17.2, U18.2, U18.3, U18.4
GND9: C38.1, C40.2, JP10.2, R38.1, U19.2, U20.2, U20.3, U20.4
GND10: C42.1, C44.2, JP11.2, R42.1, U21.2, U22.2, U22.3, U22.4
GND11: C46.1, C48.2, JP12.2, R46.1, U23.2, U24.2, U24.3, U24.4
GND12: C50.1, C52.2, JP13.2, R50.1, U25.2, U26.2, U26.3, U26.4
GND13: C54.1, C56.2, JP14.2, R54.1, U27.2, U28.2, U28.3, U28.4
GND14: C58.1, C60.2, JP15.2, R58.1, U29.2, U30.2, U30.3, U30.4
GND15: C62.1, C64.2, JP16.2, R62.1, U31.2, U32.2, U32.3, U32.4
GND16: C66.1, C68.2, JP17.2, R66.1, U33.2, U34.2, U34.3, U34.4
GND17: C70.1, C72.2, JP18.2, R70.1, U35.2, U36.2, U36.3, U36.4
GND18: C74.1, C76.2, JP19.2, R74.1, U37.2, U38.2, U38.3, U38.4
GND19: C78.1, C80.2, JP20.2, R78.1, U39.2, U40.2, U40.3, U40.4
GND20: C82.1, C84.2, JP21.2, R82.1, U41.2, U42.2, U42.3, U42.4
GND21: C86.1, C88.2, JP22.2, R86.1, U43.2, U44.2, U44.3, U44.4
GND22: C90.1, C92.2, JP23.2, R90.1, U45.2, U46.2, U46.3, U46.4
GND23: C94.1, C96.2, JP24.2, R94.1, U47.2, U48.2, U48.3, U48.4
GND24: C98.1, C100.2, JP25.2, R98.1, U49.2, U50.2, U50.3, U50.4
GND25: C102.1, C104.2, JP26.2, R102.1, U51.2, U52.2, U52.3, U52.4
GND26: C106.1, C108.2, JP27.2, R106.1, U53.2, U54.2, U54.3, U54.4
GND27: C110.1, C112.2, JP28.2, R110.1, U55.2, U56.2, U56.3, U56.4
GND28: C114.1, C116.2, JP29.2, R114.1, U57.2, U58.2, U58.3, U58.4
GND29: C118.1, C120.2, JP30.2, R118.1, U59.2, U60.2, U60.3, U60.4
GND30: C122.1, C124.2, JP31.2, R122.1, U61.2, U62.2, U62.3, U62.4
GND31: C126.1, C128.2, JP32.2, R126.1, U63.2, U64.2, U64.3, U64.4
GND32: C130.1, C132.2, JP33.2, R130.1, U65.2, U66.2, U66.3, U66.4
GND33: C134.1, C136.2, JP34.2, R134.1, U67.2, U68.2, U68.3, U68.4
GND34: C138.1, C140.2, JP35.2, R138.1, U69.2, U70.2, U70.3, U70.4
GND35: C142.1, C144.2, JP36.2, R142.1, U71.2, U72.2, U72.3, U72.4
GND36: C146.1, C148.2, JP37.2, R146.1, U73.2, U74.2, U74.3, U74.4
GND37: C150.1, C152.2, JP38.2, R150.1, U75.2, U76.2, U76.3, U76.4
GND38: C154.1, C156.2, JP39.2, R154.1, U77.2, U78.2, U78.3, U78.4
GND39: C158.1, C160.2, JP40.2, R158.1, U79.2, U80.2, U80.3, U80.4
GND40: C162.1, C164.2, JP41.2, R162.1, U81.2, U82.2, U82.3, U82.4
GND41: C166.1, C168.2, JP42.2, R166.1, U83.2, U84.2, U84.3, U84.4
GND42: C170.1, C172.2, JP43.2, R170.1, U85.2, U86.2, U86.3, U86.4
GND43: C174.1, C176.2, JP44.2, R174.1, U87.2, U88.2, U88.3, U88.4
GND44: C178.1, C180.2, JP45.2, R178.1, U89.2, U90.2, U90.3, U90.4
GND45: C182.1, C184.2, JP46.2, R182.1, U91.2, U92.2, U92.3, U92.4
GND46: C186.1, C188.2, JP47.2, R186.1, U93.2, U94.2, U94.3, U94.4
GND47: C190.1, C192.2, JP48.2, R190.1, U95.2, U96.2, U96.3, U96.4
GND48: C194.1, C196.2, JP49.2, R194.1, U97.2, U98.2, U98.3, U98.4
GND49: C198.1, C200.2, JP50.2, R198.1, U99.2, U100.2, U100.3, U100.4
GND50: C202.1, C204.2, JP51.2, R202.1, U101.2, U102.2, U102.3, U102.4
GND51: C206.1, C208.2, JP52.2, R206.1, U103.2, U104.2, U104.3, U104.4
GND52: C210.1, C212.2, JP53.2, R210.1, U105.2, U106.2, U106.3, U106.4
GND53: C214.1, C216.2, JP54.2, R214.1, U107.2, U108.2, U108.3, U108.4
GND54: C218.1, C220.2, JP55.2, R218.1, U109.2, U110.2, U110.3, U110.4
GND55: C222.1, C224.2, JP56.2, R222.1, U111.2, U112.2, U112.3, U112.4
GND56: C226.1, C228.2, JP57.2, R226.1, U113.2, U114.2, U114.3, U114.4
GND57: C230.1, C232.2, JP58.2, R230.1, U115.2, U116.2, U116.3, U116.4
GND58: C234.1, C236.2, JP59.2, R234.1, U117.2, U118.2, U118.3, U118.4
GND59: C238.1, C240.2, JP60.2, R238.1, U119.2, U120.2, U120.3, U120.4
GND60: C242.1, C244.2, JP61.2, R242.1, U121.2, U122.2, U122.3, U122.4
GND61: C246.1, C248.2, JP62.2, R246.1, U123.2, U124.2, U124.3, U124.4
GND62: C250.1, C252.2, JP63.2, R250.1, U125.2, U126.2, U126.3, U126.4
GND63: C254.1, C256.2, JP64.2, R254.1, U127.2, U128.2, U128.3, U128.4
GND64: C258.1, C260.2, JP65.2, R258.1, U129.2, U130.2, U130.3, U130.4
GND65: C262.1, C264.2, JP66.2, R262.1, U131.2, U132.2, U132.3, U132.4
GND66: C266.1, C268.2, JP67.2, R266.1, U133.2, U134.2, U134.3, U134.4
GND67: C270.1, C272.2, JP68.2, R270.1, U135.2, U136.2, U136.3, U136.4
GND68: C274.1, C276.2, JP69.2, R274.1, U137.2, U138.2, U138.3, U138.4
GND69: C278.1, C280.2, JP70.2, R278.1, U139.2, U140.2, U140.3, U140.4
GND70: C282.1, C284.2, JP71.2, R282.1, U141.2, U142.2, U142.3, U142.4
GND71: C286.1, C288.2, JP72.2, R286.1, U143.2, U144.2, U144.3, U144.4
GND72: C290.1, C292.2, JP73.2, R290.1, U145.2, U146.2, U146.3, U146.4
GND73: C294.1, C296.2, JP74.2, R294.1, U147.2, U148.2, U148.3, U148.4
GND74: C298.1, C300.2, JP75.2, R298.1, U149.2, U150.2, U150.3, U150.4
GND75: C302.1, C304.2, JP76.2, R302.1, U151.2, U152.2, U152.3, U152.4
GND76: C306.1, C308.2, JP77.2, R306.1, U153.2, U154.2, U154.3, U154.4
GND77: C310.1, C312.2, JP78.2, R310.1, U155.2, U156.2, U156.3, U156.4
GND78: C314.1, C316.2, JP79.2, R314.1, U157.2, U158.2, U158.3, U158.4
GND79: C318.1, C320.2, JP80.2, R318.1, U159.2, U160.2, U160.3, U160.4
GND80: C322.1, C324.2, JP81.2, R322.1, U161.2, U162.2, U162.3, U162.4
GND81: C326.1, C328.2, JP82.2, R326.1, U163.2, U164.2, U164.3, U164.4
GND82: C330.1, C332.2, JP83.2, R330.1, U165.2, U166.2, U166.3, U166.4
GND83: C334.1, C336.2, JP84.2, R334.1, U167.2, U168.2, U168.3, U168.4
GND84: C338.1, C340.2, JP85.2, R338.1, U169.2, U170.2, U170.3, U170.4
GND85: C342.1, C344.2, JP86.2, R342.1, U171.2, U172.2, U172.3, U172.4
GND86: C346.1, C348.2, JP87.2, R346.1, U173.2, U174.2, U174.3, U174.4
GND87: C350.1, C352.2, JP88.2, R350.1, U175.2, U176.2, U176.3, U176.4
GND88: C354.1, C356.2, JP89.2, R354.1, U177.2, U178.2, U178.3, U178.4
GND89: C358.1, C360.2, JP90.2, R358.1, U179.2, U180.2, U180.3, U180.4
GND90: C362.1, C364.2, JP91.2, R362.1, U181.2, U182.2, U182.3, U182.4
GND91: C366.1, C368.2, JP92.2, R366.1, U183.2, U184.2, U184.3, U184.4
GND92: C370.1, C372.2, JP93.2, R370.1, U185.2, U186.2, U186.3, U186.4
GND93: C374.1, C376.2, JP94.2, R374.1, U187.2, U188.2, U188.3, U188.4
GND94: C378.1, C380.2, JP95.2, R378.1, U189.2, U190.2, U190.3, U190.4
GND95: C382.1, C384.2, JP96.2, R382.1, U191.2, U192.2, U192.3, U192.4
GND96: C386.1, C388.2, JP97.2, R386.1, U193.2, U194.2, U194.3, U194.4
GND97: C390.1, C392.2, JP98.2, R390.1, U195.2, U196.2, U196.3, U196.4
GND98: C394.1, C396.2, JP99.2, R394.1, U197.2, U198.2, U198.3, U198.4
GND99: C398.1, C400.2, JP100.2, R398.1, U199.2, U200.2, U200.3, U200.4
GND100: C402.1, C404.2, JP101.2, R402.1, U201.2, U202.2, U202.3, U202.4
GND101: C406.1, C408.2, JP102.2, R406.1, U203.2, U204.2, U204.3, U204.4
GND102: C410.1, C412.2, JP103.2, R410.1, U205.2, U206.2, U206.3, U206.4
GND103: C414.1, C416.2, JP104.2, R414.1, U207.2, U208.2, U208.3, U208.4
GND104: C418.1, C420.2, JP105.2, R418.1, U209.2, U210.2, U210.3, U210.4
GND105: C422.1, C424.2, JP106.2, R422.1, U211.2, U212.2, U212.3, U212.4
GND106: C426.1, C428.2, JP107.2, R426.1, U213.2, U214.2, U214.3, U214.4
GND107: C430.1, C432.2, JP108.2, R430.1, U215.2, U216.2, U216.3, U216.4
GND108: C434.1, C436.2, JP109.2, R434.1, U217.2, U218.2, U218.3, U218.4
GND109: C438.1, C440.2, JP110.2, R438.1, U219.2, U220.2, U220.3, U220.4
GND110: C442.1, C444.2, JP111.2, R442.1, U221.2, U222.2, U222.3, U222.4
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

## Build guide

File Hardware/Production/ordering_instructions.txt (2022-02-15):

panel size, 187x120mm
PCB thickness, 1.6mm
number of layers, 2
soldermask color, Red
silkscreen color, White
oz copper, 1oz
finish, HASL lead free
stencils, top
pcs per panel, 120
min trace width, 0.2540mm / 0.0100in
min drill size, 0.3810mm / 0.0150in

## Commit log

2022-02-10 Prod_ID for mic
    -also moved Via away from pad 6
    -and routed a tiny airwire on VCC pad
    [SparkFun_Analog_MEMS_Microphone_Breakout_SPH8878LR5H-1.brd, SparkFun_Analog_MEMS_Microphone_Breakout_SPH8878LR5H-1.sch]
2022-02-11 Added test point for OUT-
    [SparkFun_Analog_MEMS_Microphone_Breakout_SPH8878LR5H-1.brd, SparkFun_Analog_MEMS_Microphone_Breakout_SPH8878LR5H-1.sch]
2022-02-14 Checklist catches
    -Attribution for original design
    -test point for OUT- moved to 50 though grid
    -nudges some vias to avoid silk
    -adjust value text objects for assembly sheet
    [SparkFun_Analog_MEMS_Microphone_Breakout_SPH8878LR5H-1.brd, SparkFun_Analog_MEMS_Microphone_Breakout_SPH8878LR5H-1.sch]
2022-02-15 Production panel BRD and Gerbers v10
    [SparkFun_Analog_MEMS_Microphone_Breakout_SPH8878LR5H-1-Panel.brd]
2022-03-16 Update README.md
    Updating README with current photos and product links.

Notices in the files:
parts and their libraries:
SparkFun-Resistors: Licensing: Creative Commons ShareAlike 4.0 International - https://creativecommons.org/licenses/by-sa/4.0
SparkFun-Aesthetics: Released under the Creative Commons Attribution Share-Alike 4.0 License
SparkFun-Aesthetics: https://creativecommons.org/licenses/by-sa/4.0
